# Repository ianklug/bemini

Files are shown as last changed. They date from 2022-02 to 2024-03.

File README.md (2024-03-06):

# Bemini
A miniature mechanical keyboard controller with a rotary encoder for staggered-key rhythm games.

Bemini PCB

Design by [ianklug](https://ianklug.com). Art by [clue](https://clue.graphics).

Special thanks to [Sebastiaan Swinkels](https://github.com/C44Supra) for technical assistance.

Made with [KiCad](https://www.kicad.org/) and [Blender](https://www.blender.org/).

*Please clone this repository using the `--recurse-submodules` flag. Some of the required symbol and footprint libraries will not be included otherwise.*

## Versions

*Please note that the RP2040 models are functional at a hardware level, but software is incomplete.*

The 2.x versions (bemini-rp) use the RP2040 MCU, and require different firmware from the 1.x versions. They also include a few new features and refinements over the 1.x models, including M2 mounting holes and an RGB indicator LED.

The 1.x versions (bemini-atmel) use the Atmega32U4 MCU, in either the MU or AU footprint. These versions are no longer recommended.

## Firmware

Bemini is powered by [QMK Firmware](https://qmk.fm).

Bemini ships with a customized keymap that is ideal for use with many common rhythm games. More information about the default keymap is available [here](https://kayboards.com/pages/bemini-keymap).

You may customize Bemini's keymap by following the instructions in [these documents](https://docs.qmk.fm). This will require a reflash of your board's firmware. Use [QMK Toolbox](https://github.com/qmk/qmk_toolbox) to flash if on Windows or MacOS, or the QMK CLI with avrdude on Linux.

## Printed Parts

The .stl files for Bemini's 3D-printed parts are included in the models directory. I print these parts on a [Prusa i3 MK3S](https://www.prusa3d.com/category/original-prusa-i3-mk3s/) in black PLA on a smooth steel print bed.

The newer turntable (v2) is a single piece, and requires no supports. It should be printed with the top facing down. Infill should be at least 15%. This is the recommended version.

The first turntable (v1) prints in two pieces (main and cap) which snap together. This may improve the quality of some of the touch surfaces if your prints are inconsistent. Print with the flat top of the cap facing down, and the flat ring (the bottom) of the main body facing down. The body will require supports.

The encoder retainer should be printed with the flat part facing down. Slide this piece in between the encoder's legs on the underside of the board to secure the encoder, if you do not wish to solder it in place.

## Manufacturing

**Manufacture at your own risk. I can not guarantee the quality or functionality of boards which are not sold directly by me.**

**Please note that most PCB manufacturers have a minimum order quantity of five units.**

Hand-soldering Beminis from scratch is extremely difficult and NOT recommended due to the small size of the surface-mount components and their pads. Instead, PCB assembly services can source and assemble all the small parts on the bottom of the board. Depending on the manufacturer, you may only need to hand-solder some of the larger parts, such as the USB port and the switch sockets.

I can personally recommend [JLCPCB](https://jlcpcb.com) or [PCBWay](https://pcbway.com/), but most PCB manufacturers should be capable of producing Bemini.

Zipped gerber files are present for the production designs of each variation of Bemini. They are called `<variation>-gerbers-<version>.zip` and should be compatible with most PCB manufacturing services.

If you will be ordering from JLCPCB, use `<variation>-gerbers-jlcpcb-<version>.zip`. These gerbers have the JLCPCB serial number placed in an easily-readable location on the back of the board. Make sure to choose "Specify a location" under "Remove Order Number" so that this number is printed where expected.

Production Beminis are two-layer FR4, 1.6mm thick. The RP2040 versions measure 220x70mm. They are assembled using lead-free solder. BOM and Centroid files are present for each board in the format expected by JLCPCB.

The USB connector is a [GCT USB4085](https://gct.co/connector/usb4085). The hot-swap sockets are [Kailh sockets](https://www.kailhswitch.com/mechanical-keyboard-switches/box-switches/mechanical-keyboard-switches-kailh-pcb-socket.html). The encoder sockets are [Mill-Max 3305 receptacles](https://www.mill-max.com/products/receptacle/3305). The encoder is a [Bourns PES12](https://www.bourns.com/pdfs/pes12.pdf). An [Alps EC12E](https://tech.alpsalpine.com/e/products/category/encorder/sub/02/series/ec12e/) will also work. The RGB LED is a WS2812B.

## License

Shield: [][cc-by-sa]

This work is licensed under a
[Creative Commons Attribution-ShareAlike 4.0 International License][cc-by-sa].

[][cc-by-sa]

[cc-by-sa]: http://creativecommons.org/licenses/by-sa/4.0/
[cc-by-sa-image]: https://licensebuttons.net/l/by-sa/4.0/88x31.png
[cc-by-sa-shield]: https://img.shields.io/badge/License-CC%20BY--SA%204.0-lightgrey.svg

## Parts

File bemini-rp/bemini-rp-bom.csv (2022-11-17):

Comment | Designator | Footprint | LCSC Part Number
10uF | C1, C2 | 402 | C15525
100nF | C3, C8, C9, C10, C11, C12, C13, C14, C15, C16 | 402 | C1525
1uF | C4, C5 | 402 | C52923
10pF | C6, C7 | 402 | C32949
Schottky | D1 | SOD-323 | C191023
500mA | F1 | 805 | C261942
BSS138 | Q1 | SOT-25 | C400505
10k | R7, R9, R10 | 402 | C25744
5.1k | R2, R3 | 402 | C25905
22 | R4, R5 | 402 | C25092
1k | R6, R8 | 402 | C25905
TS-1187A-B-A-B | SW1, SW2 | SMD | C318884
RP2040 | U1 | QFN-56(7x7) | C2040
W25Q128JV | U2 | WSON-8_5x6mm | C190862
3.3V | U3 | SOT-25 | C51118
12MHz | Y1 | SMD3225-4P | C255903

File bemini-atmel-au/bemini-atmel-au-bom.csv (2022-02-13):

Comment | Designator | Footprint | LCSC Part Number
4.7nF | C1 | 402 | C1538
1uF | C2 | 402 | C52923
100nF | C3, C4, C5 | 402 | C1525
10uF | C6 | 402 | C15525
22pF | C7, C8 | 402 | C1555
1M | R1 | 402 | C26083
5.1k | R2, R3 | 402 | C25905
22 | R4, R5 | 402 | C25092
10k | R6, R7 | 402 | C25744
500mA | F1 | 805 | C261942
ATmega32U4-AU | U1 | TQFP-44_10.0x10.0x0.8P | C44854
16MHz | X1 | SMD-3225_4P | C13738
TS-1187A-B-A-B | S1 | SMD-SW-4_5.1x5.1x1.5 | C318884

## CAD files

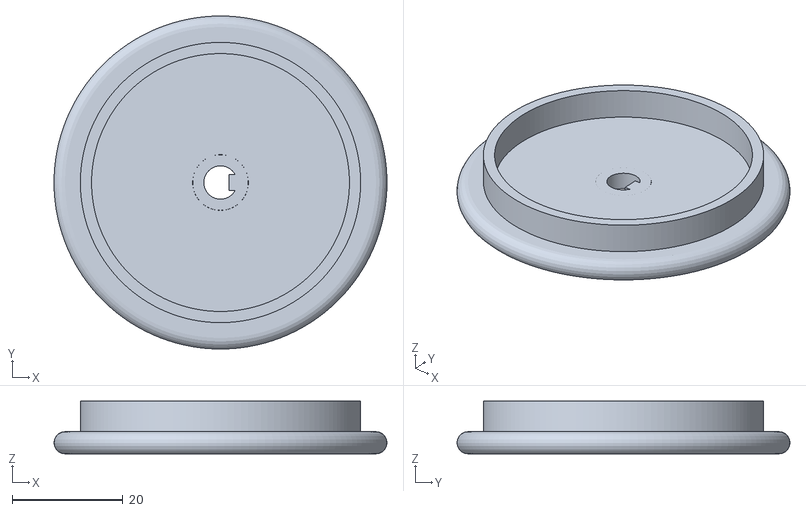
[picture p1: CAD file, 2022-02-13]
models/turntable-v1-main.stl
60.0 x 60.0 x 9.50

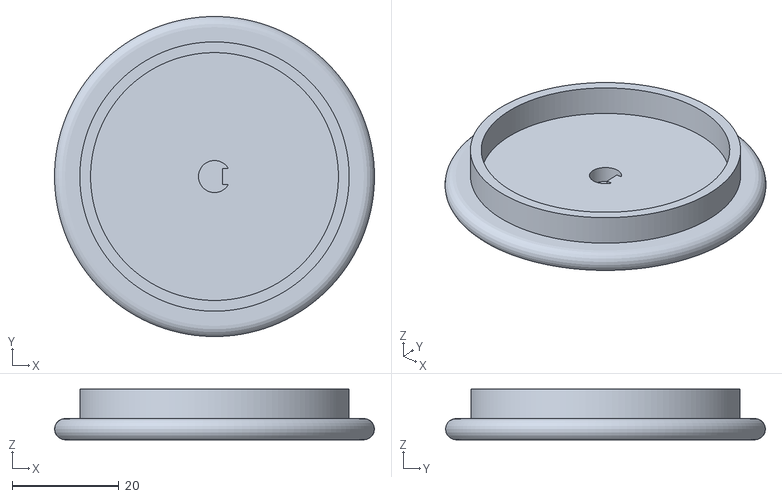
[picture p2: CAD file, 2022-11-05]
models/turntable-v2.stl
60.0 x 60.0 x 9.50

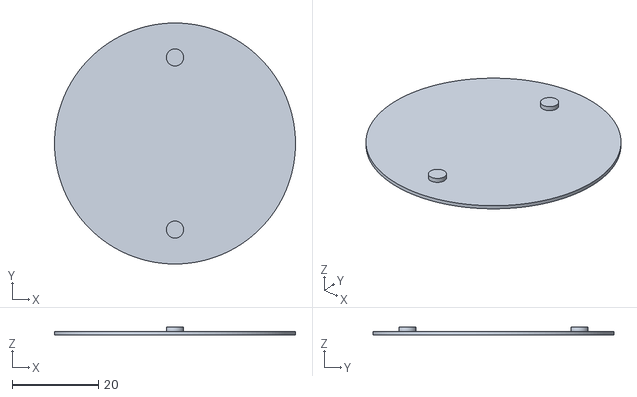
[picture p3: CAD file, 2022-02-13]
models/turntable-v1-cap.stl
56.0 x 56.0 x 1.80

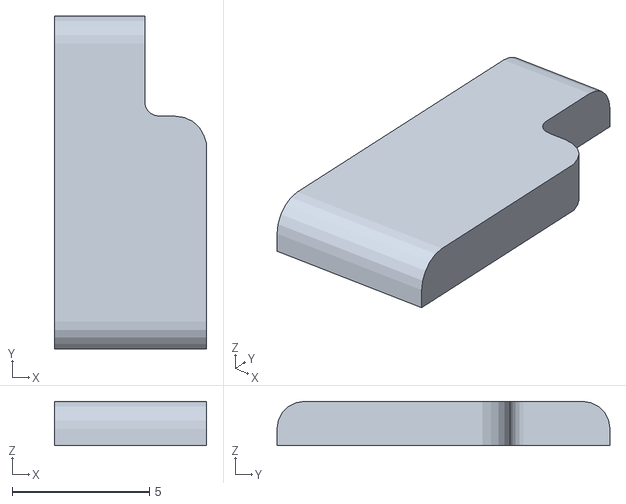
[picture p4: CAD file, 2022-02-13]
models/encoder-retainer.stl
5.55 x 12.1 x 1.61

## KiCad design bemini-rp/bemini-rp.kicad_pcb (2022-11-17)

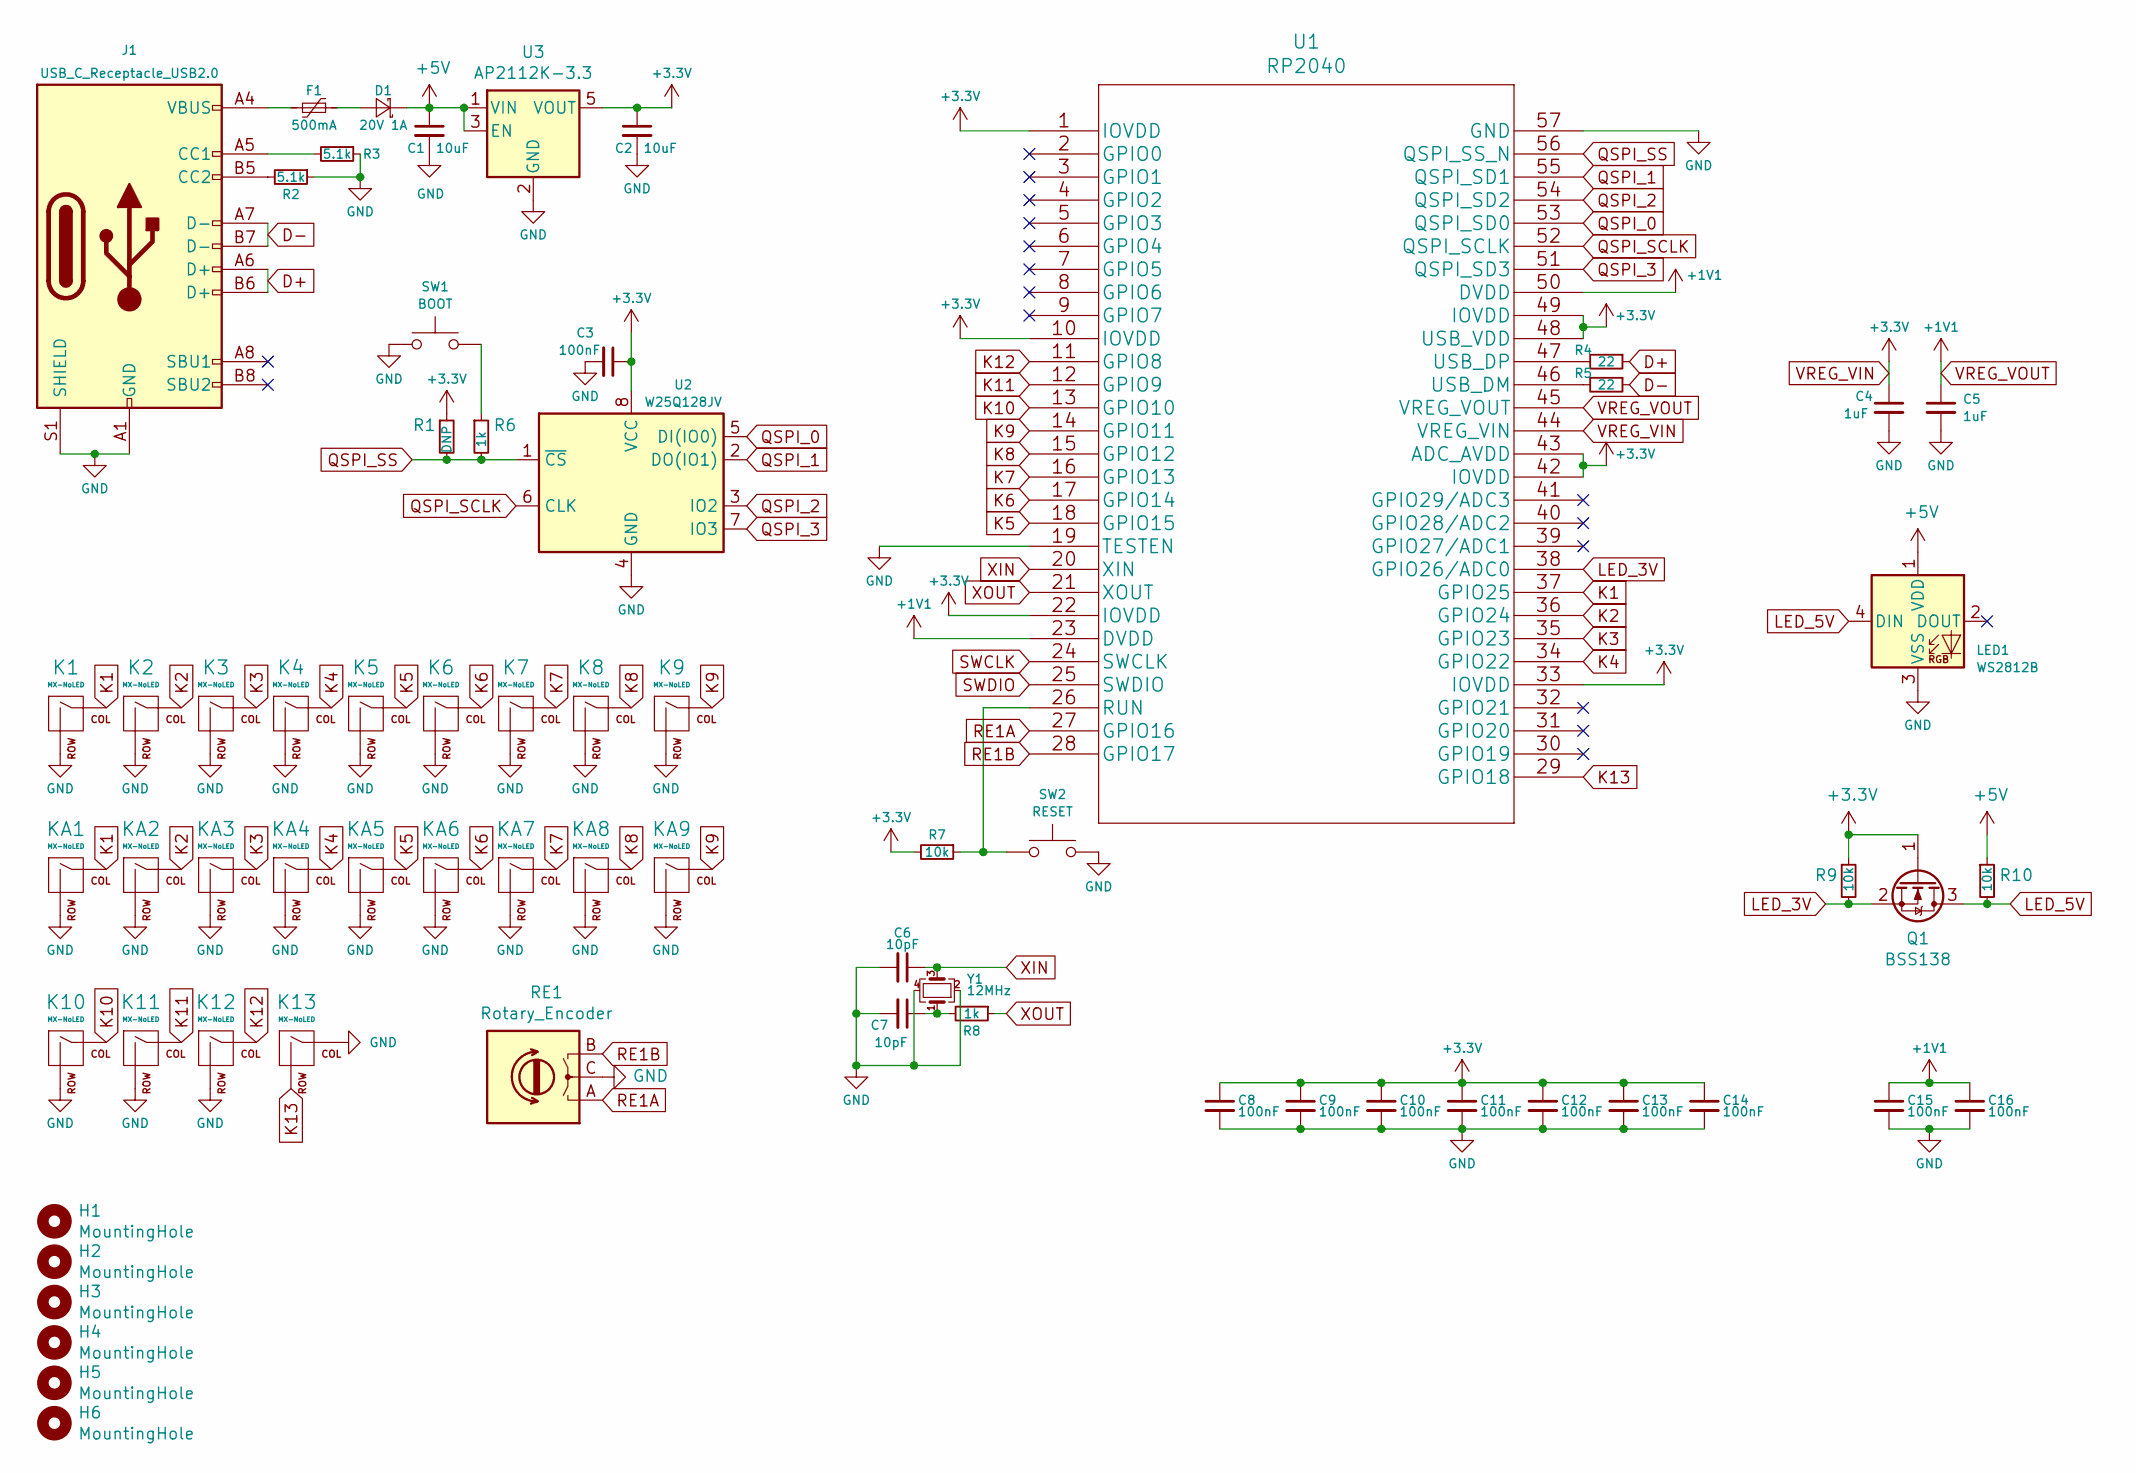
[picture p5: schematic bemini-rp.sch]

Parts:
C1, C2: 10uF; C_0402
C3, C8, C9, C10, C11, C12, C13, C14, C15, C16: 100nF; C_0402
C4, C5: 1uF; C_0402
C6, C7: 10pF; C_0402
D1: 20V 1A; D_SOD-323
F1: 500mA; Fuse_0805
H1, H2, H3, H4, H5, H6: MountingHole; MountingHole_2.2mm_M2
J1: USB_C_Receptacle_USB2.0; USB_C_GCT_USB4085
K1, K2, K3, K4, K5, K6, K7, K8, K9, K10, K11, K12, K13: MX-NoLED; Kailh_socket_PG1350
KA1, KA2, KA3, KA4, KA5, KA6, KA7, KA8, KA9: MX-NoLED; Kailh_socket_PG1350
LED1: WS2812B
Q1: BSS138; SOT-23
R1: DNP; R_0402
R2, R3: 5.1k; R_0402
R4, R5: 22; R_0402
R6, R8: 1k; R_0402
R7, R9, R10: 10k; R_0402
RE1: Rotary_Encoder; RotaryEncoder_Alps_EC12E_Vertical_H20mm
SW1: BOOT; TS-1187A-B-A-B
SW2: RESET; TS-1187A-B-A-B
U1: RP2040
U2: W25Q128JV; W25Q128JVPIQ
U3: AP2112K-3.3; SOT-23-5
Y1: 12MHz; Crystal_SMD_3225-4pin_3.2x2.5mm

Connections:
+5V: C1.1, D1.1 (K), LED1.1 (VDD), R10.1, U3.1 (VIN), U3.3 (EN)
D+: J1.A6 (D+), J1.B6 (D+), R4.1
D-: J1.A7 (D-), J1.B7 (D-), R5.1
GND: C1.2, C2.2, C3.2, C4.2, C5.2, C6.2, C7.2, C8.2, C9.2, C10.2, C11.2, C12.2, C13.2, C14.2, C15.2, C16.2, J1.A1 (GND), J1.A12 (GND), J1.B1 (GND), J1.B12 (GND), J1.S1 (SHIELD), K1.2 (ROW), K2.2 (ROW), K3.2 (ROW), K4.2 (ROW), K5.2 (ROW), K6.2 (ROW), K7.2 (ROW), K8.2 (ROW), K9.2 (ROW), K10.2 (ROW), K11.2 (ROW), K12.2 (ROW), K13.1 (COL), KA1.2 (ROW), KA2.2 (ROW), KA3.2 (ROW), KA4.2 (ROW), KA5.2 (ROW), KA6.2 (ROW), KA7.2 (ROW), KA8.2 (ROW), KA9.2 (ROW), LED1.3 (VSS), R2.1, R3.1, RE1.C, SW1.1, SW2.2, U1.19 (TESTEN), U1.57 (GND), U2.4 (GND), U3.2 (GND), Y1.2, Y1.4
K1: K1.1 (COL), KA1.1 (COL), U1.37 (GPIO25)
K2: K2.1 (COL), KA2.1 (COL), U1.36 (GPIO24)
K3: K3.1 (COL), KA3.1 (COL), U1.35 (GPIO23)
K4: K4.1 (COL), KA4.1 (COL), U1.34 (GPIO22)
K5: K5.1 (COL), KA5.1 (COL), U1.18 (GPIO15)
K6: K6.1 (COL), KA6.1 (COL), U1.17 (GPIO14)
K7: K7.1 (COL), KA7.1 (COL), U1.16 (GPIO13)
K8: K8.1 (COL), KA8.1 (COL), U1.15 (GPIO12)
K9: K9.1 (COL), KA9.1 (COL), U1.14 (GPIO11)
K10: K10.1 (COL), U1.13 (GPIO10)
K11: K11.1 (COL), U1.12 (GPIO9)
K12: K12.1 (COL), U1.11 (GPIO8)
K13: K13.2 (ROW), U1.29 (GPIO18)
LED_3V: Q1.2 (S), R9.2, U1.38 (GPIO26/ADC0)
LED_5V: LED1.4 (DIN), Q1.3 (D), R10.2
unnamed: C7.1, R8.2, Y1.1
unnamed: D1.2 (A), F1.1
unnamed: F1.2, J1.A4 (VBUS), J1.A9 (VBUS), J1.B4 (VBUS), J1.B9 (VBUS)
unnamed: J1.A5 (CC1), R3.2
unnamed: J1.B5 (CC2), R2.2
unnamed: R4.2, U1.47 (USB_DP)
unnamed: R5.2, U1.46 (USB_DM)
unnamed: R6.1, SW1.2
unnamed: R7.1, SW2.1, U1.26 (RUN)
QSPI_0: U1.53 (QSPI_SD0), U2.5 (DI(IO0))
QSPI_1: U1.55 (QSPI_SD1), U2.2 (DO(IO1))
QSPI_2: U1.54 (QSPI_SD2), U2.3 (IO2)
QSPI_3: U1.51 (QSPI_SD3), U2.7 (IO3)
QSPI_SCLK: U1.52 (QSPI_SCLK), U2.6 (CLK)
QSPI_SS: R1.2, R6.2, U1.56 (QSPI_SS_N), U2.1 (~CS)
RE1A: RE1.A, U1.27 (GPIO16)
RE1B: RE1.B, U1.28 (GPIO17)
VREG_VIN: C2.1, C3.1, C4.1, C8.1, C9.1, C10.1, C11.1, C12.1, C13.1, C14.1, Q1.1 (G), R1.1, R7.2, R9.1, U1.1 (IOVDD), U1.10 (IOVDD), U1.22 (IOVDD), U1.33 (IOVDD), U1.42 (IOVDD), U1.43 (ADC_AVDD), U1.44 (VREG_VIN), U1.48 (USB_VDD), U1.49 (IOVDD), U2.8 (VCC), U3.5 (VOUT)
VREG_VOUT: C5.1, C15.1, C16.1, U1.23 (DVDD), U1.45 (VREG_VOUT), U1.50 (DVDD)
XIN: C6.1, U1.20 (XIN), Y1.3
XOUT: R8.1, U1.21 (XOUT)

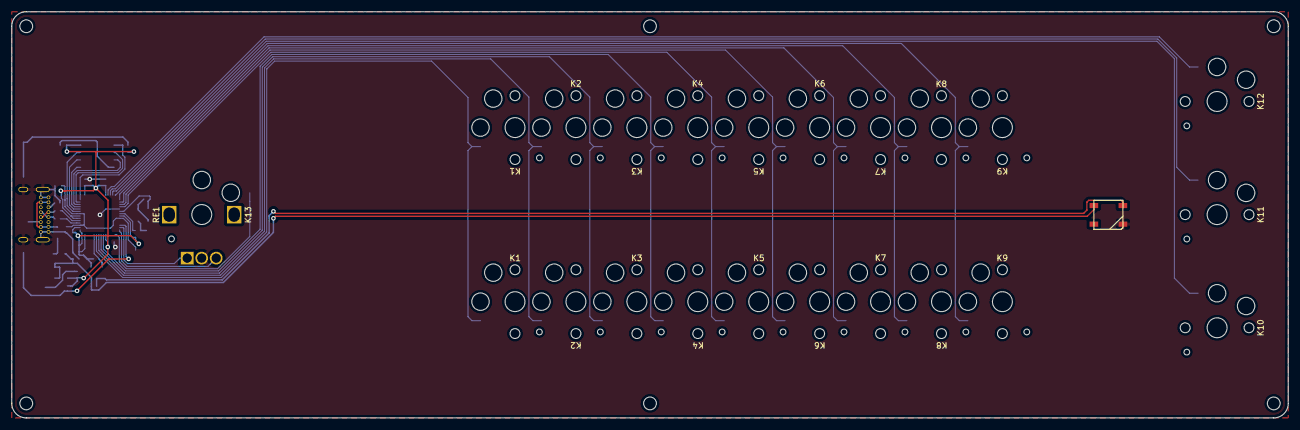
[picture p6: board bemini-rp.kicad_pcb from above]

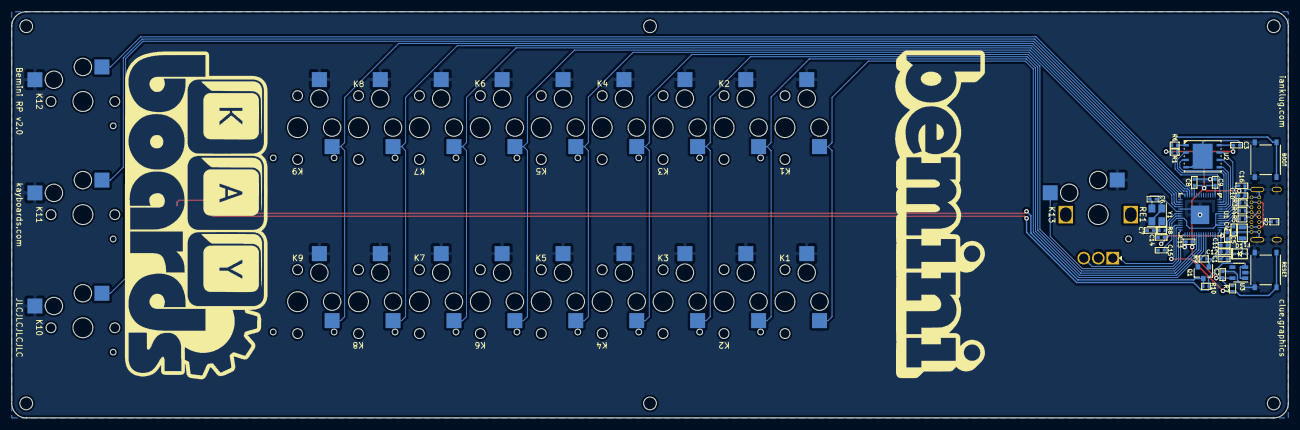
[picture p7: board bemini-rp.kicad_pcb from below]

Board: 2 copper layers, 220.0 x 70.0 mm, 66 parts (35 on the bottom side), 40 nets.

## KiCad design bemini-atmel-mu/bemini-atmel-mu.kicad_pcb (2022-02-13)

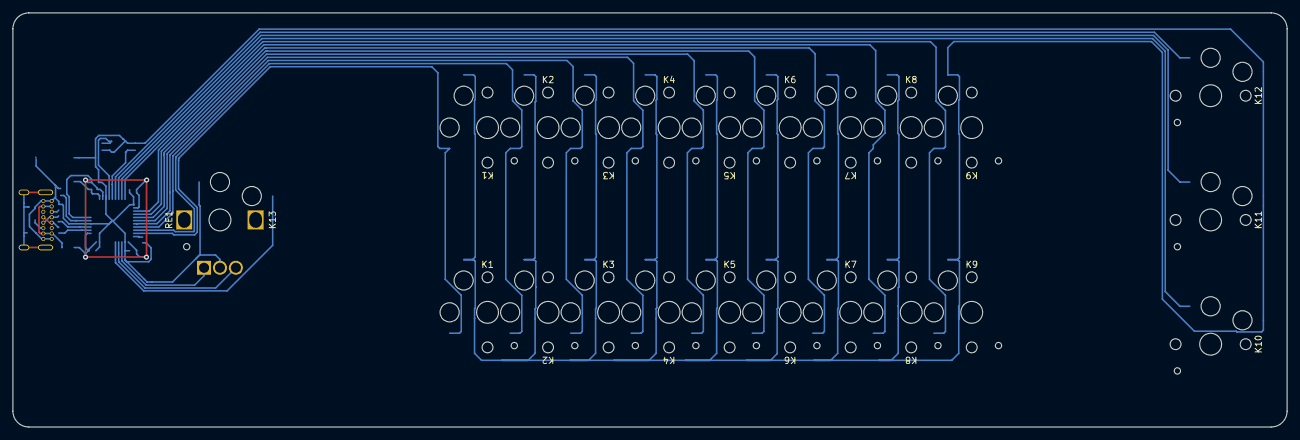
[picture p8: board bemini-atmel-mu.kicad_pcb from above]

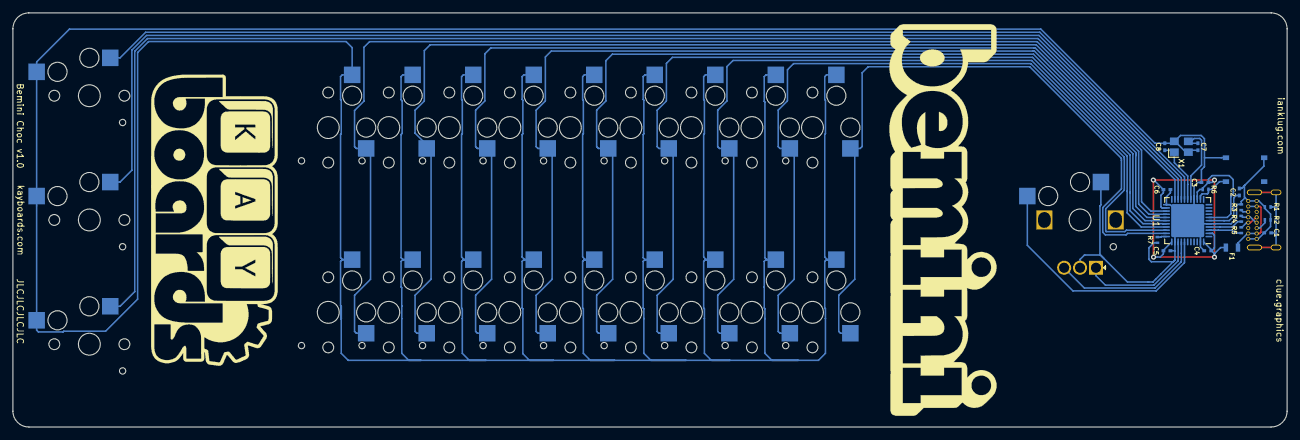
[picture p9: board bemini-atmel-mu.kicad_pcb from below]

Board: 2 copper layers, 200.0 x 65.0 mm, 43 parts (19 on the bottom side), 30 nets.

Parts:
C1: 4.7nF; C_0402
C2: 1uF; C_0402
C3, C4, C5: 0.1uF; C_0402
C6: 10uF; C_0402
C7, C8: 22pF; C_0402
F1: 500mA; Fuse_0805
J1: USB_C_Receptacle_USB2.0; USB_C_GCT_USB4085
K1, K2, K3, K4, K5, K6, K7, K8, K9, K10, K11, K12, K13: MX-NoLED; Kailh_socket_PG1350
KA1, KA2, KA3, KA4, KA5, KA6, KA7, KA8, KA9: MX-NoLED; Kailh_socket_PG1350
R1: 1M; R_0402
R2, R3: 5.1k; R_0402
R4, R5: 22; R_0402
R6, R7: 10k; R_0402
RE1: Rotary_Encoder; RotaryEncoder_Alps_EC12E_Vertical_H20mm
S1: SW_Push; TS-1187A-B-A-B
U1: ATmega32U4-MU; QFN-44-1EP_7x7mm_P0.5mm_EP5.2x5.2mm
X1: 16MHz; Crystal_SMD_3225-4pin_3.2x2.5mm

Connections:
D+: R4.1, U1.4
D-: R5.1, U1.3
GND: C1.2, C2.2, C3.2, C4.2, C5.2, C6.2, C7.1, C8.1, J1.A1, J1.A12, J1.B1, J1.B12, K1.2, K2.2, K3.2, K4.2, K5.2, K6.2, K7.2, K8.2, K9.2, K10.2, K11.2, K12.2, K13.1, KA1.2, KA2.2, KA3.2, KA4.2, KA5.2, KA6.2, KA7.2, KA8.2, KA9.2, R1.2, R2.1, R3.1, R7.1, RE1.C, S1.1, U1.5, U1.15, U1.23, U1.35, U1.43, U1.45, X1.2, X1.4
K1: K1.1, KA1.1, U1.32
K2: K2.1, KA2.1, U1.31
K3: K3.1, KA3.1, U1.30
K4: K4.1, KA4.1, U1.29
K5: K5.1, KA5.1, U1.28
K6: K6.1, KA6.1, U1.27
K7: K7.1, KA7.1, U1.26
K8: K8.1, KA8.1, U1.25
K9: K9.1, KA9.1, U1.21
K10: K10.1, U1.20
K11: K11.1, U1.19
K12: K12.1, U1.18
K13: K13.2, U1.38
unnamed: C1.1, J1.S1, R1.1
unnamed: C2.1, U1.6
unnamed: C7.2, U1.16, X1.3
unnamed: C8.2, U1.17, X1.1
unnamed: F1.2, J1.A4, J1.A9, J1.B4, J1.B9
unnamed: J1.A5, R3.2
unnamed: J1.A6, J1.B6, R4.2
unnamed: J1.A7, J1.B7, R5.2
unnamed: J1.B5, R2.2
unnamed: R7.2, U1.33
RE1A: RE1.A, U1.36
RE1B: RE1.B, U1.37
RST: R6.2, S1.2, U1.13
VCC: C3.1, C4.1, C5.1, C6.1, F1.1, R6.1, U1.2, U1.7, U1.14, U1.24, U1.34, U1.44

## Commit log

2022-11-05 initial rp2040 commit
    [bemini-atmel-au-bom.csv, bemini-atmel-au.kicad_pcb, bemini-atmel-au.sch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]
2022-11-17 fix incorrect resistor part number in BOM
    [bemini-rp-bom.csv]
2022-11-17 update usb resistors
    [bemini-rp-bom.csv, bemini-rp.kicad_pcb, bemini-rp.sch]

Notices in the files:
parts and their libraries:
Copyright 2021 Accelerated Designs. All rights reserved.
